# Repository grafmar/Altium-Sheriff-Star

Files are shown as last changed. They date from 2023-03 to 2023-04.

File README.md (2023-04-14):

# Altium-Sheriff-Star
PCB with Sherif-Star shape and 6 animated LEDs on it. It has the Altium Logo on the front and the Text "SHERIFF".
I also designed a holder to display the sheriff star on your desk.

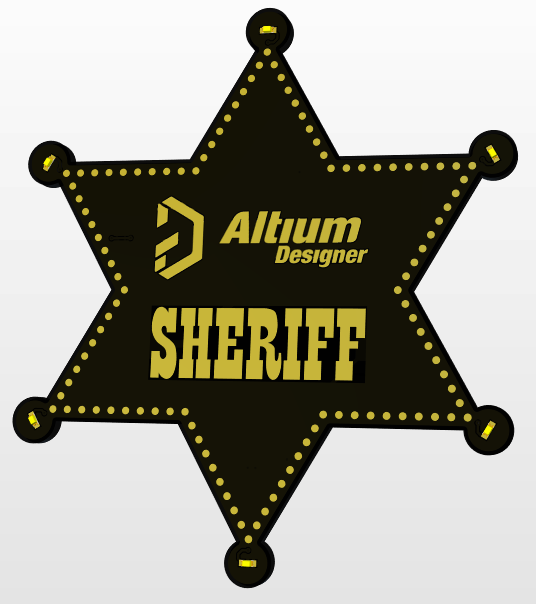
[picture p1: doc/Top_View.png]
PCB Top View
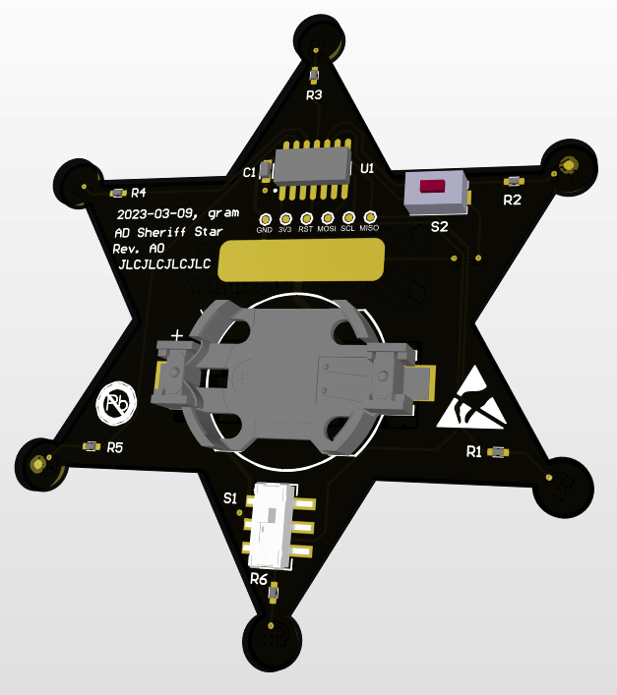
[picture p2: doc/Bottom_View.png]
PCB Bottom View
Animated GIF  

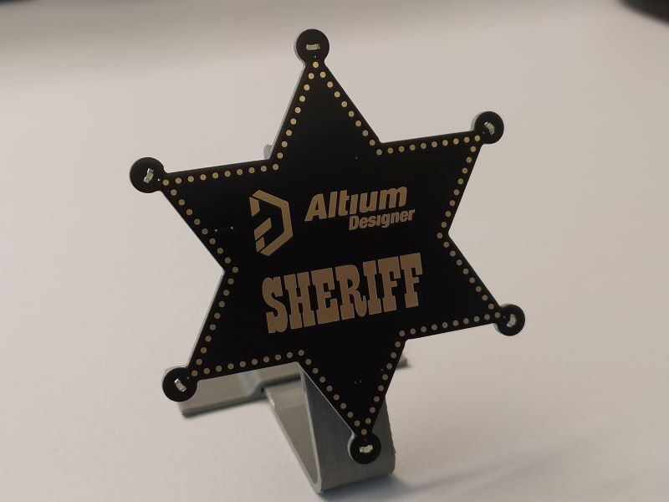
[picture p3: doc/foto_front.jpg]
Foto Front
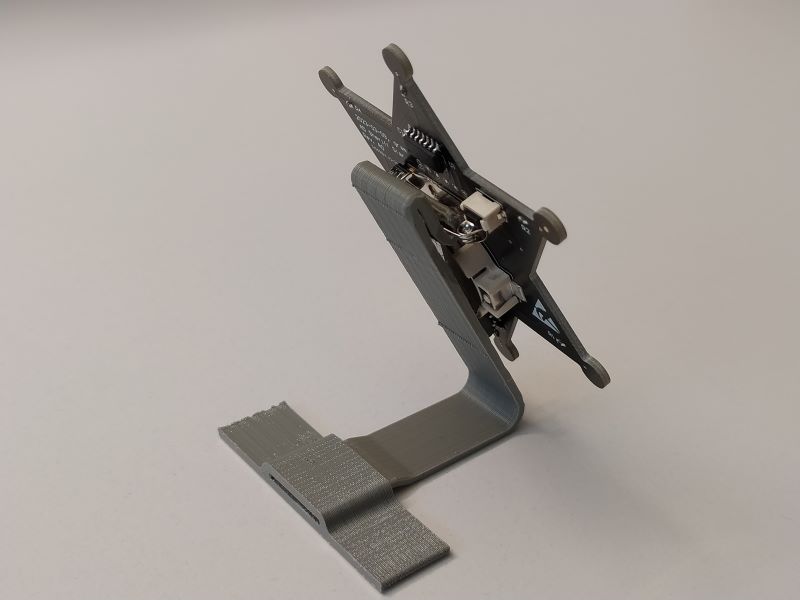
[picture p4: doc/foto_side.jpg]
Foto Side
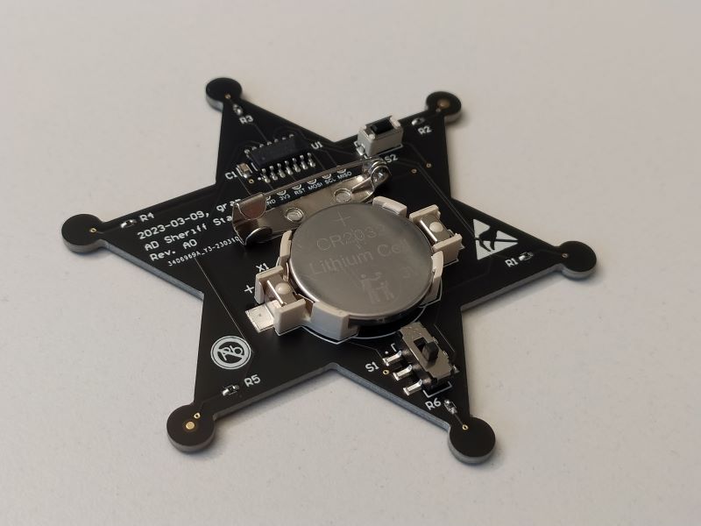
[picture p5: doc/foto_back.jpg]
Foto Back
  

## SW-Requirements
* [Arduino IDE](https://www.arduino.cc/en/main/software) (V 2.0.4)
* Board support "ATtiny/ATmega Standalone" (V 0.1.0)

## Hardware
The hardware consists of:
* [PCB Altium Sheriff Star](https://github.com/grafmar/Altium-Sheriff-Star/tree/main/pcb):
  * 6x Yellow LED 0603
  * 6x 100&Omega; 0402
  * 1x ATTINY84A-SSU
  * 1x CR2032 holder with CR2032 battery (Renata, SMTU2032-LF)
  * 1x slide switch (C&K, JS202011SCQN)
  * 1x tactile switch (Alps, SKQMASE010)
  * 1x 100nF 060
  * 1x 25mm [Safety Pins Brooch](https://www.aliexpress.com/item/4000026759489.html)

Schematics:

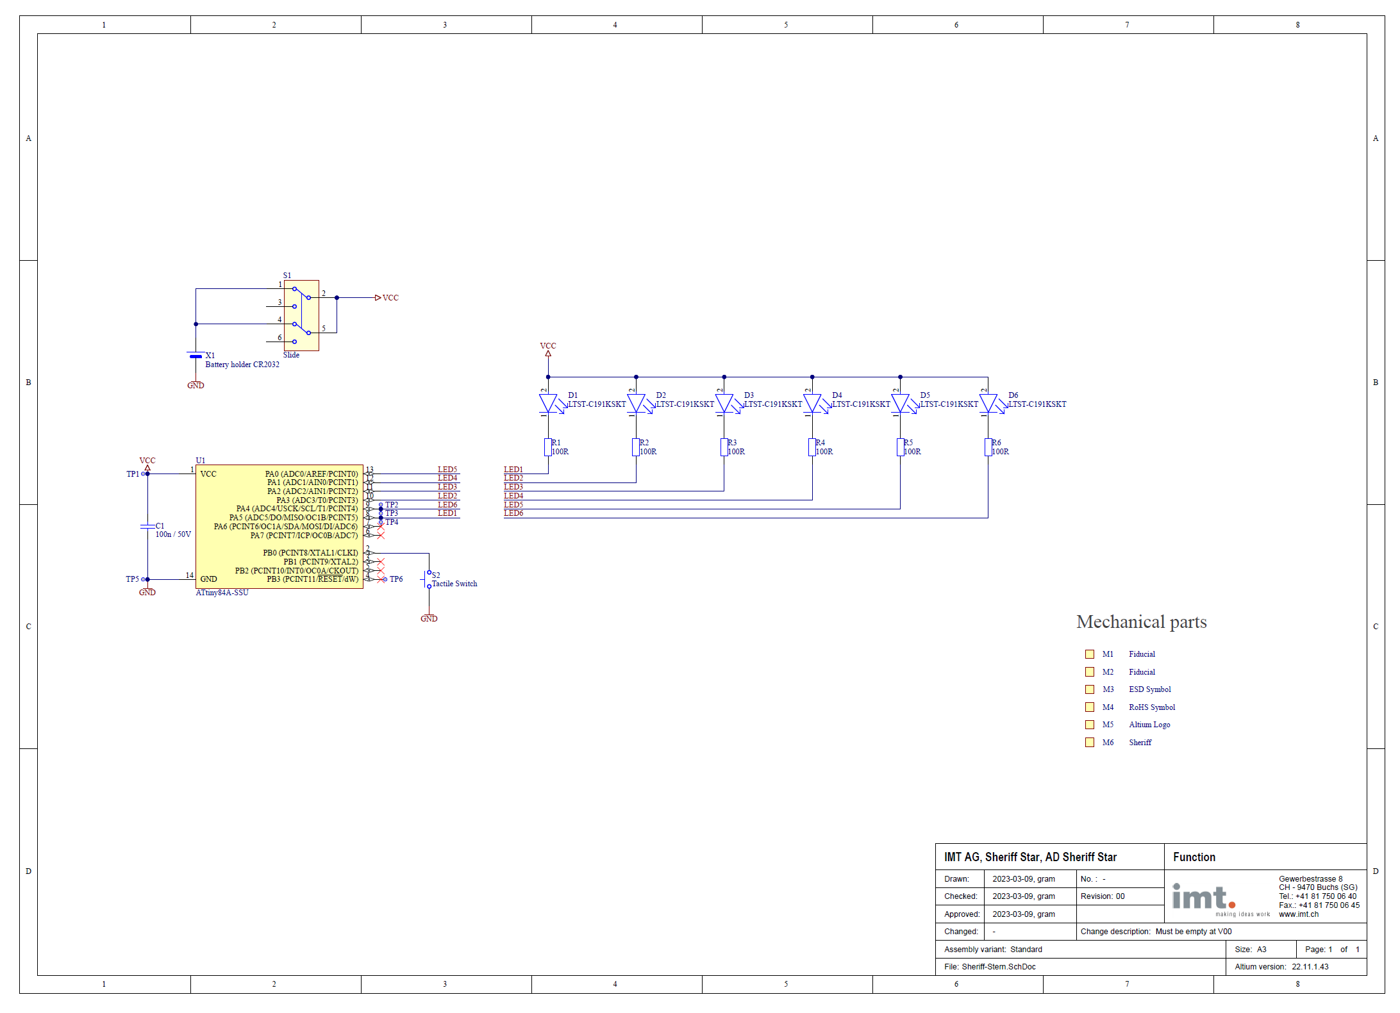
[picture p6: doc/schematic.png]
Schematics
[](pcb/30%20Production%20data/Rev00,%20A0/Schematic%20AD%20Sheriff%20Star%20Sheriff%20Star%20Rev00.PDF)

## Holder
The holder is designed in [FreeCAD](https://www.freecad.org/) and printed on a 3D printer. It has a small groove on the top to put the needle in. Like this it stands stable on the office table.

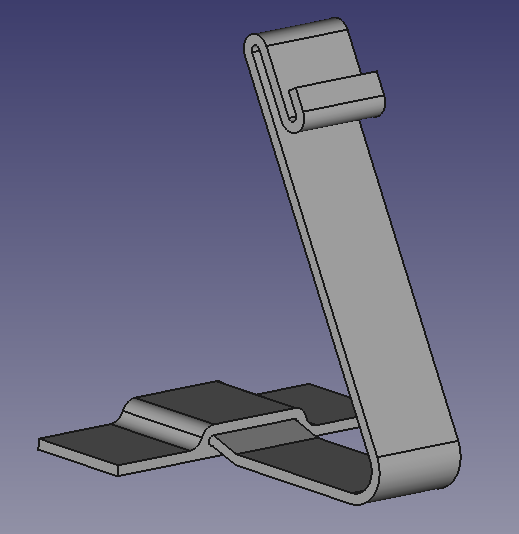
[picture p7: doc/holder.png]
Holder
 

## Author
[Marco Graf](https://github.com/grafmar)

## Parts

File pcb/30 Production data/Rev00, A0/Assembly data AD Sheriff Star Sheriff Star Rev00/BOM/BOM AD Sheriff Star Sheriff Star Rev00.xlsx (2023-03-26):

CUSTOMER, PROJECT |  |  | <Parameter VarCustomer not found> | <Parameter VarProjectName not found> | NUMBER | DESCRIPTION |  | REVISION
IMT AG, Sheriff Star |  |  |  |  | - | AD Sheriff Star |  | 00
CREATED |  |  |  |  | ASSEMBLY VARIANT
2023-03-09, gram |  |  |  |  | Standard
CHECKED
2023-03-09, gram
APPROVED
2023-03-09, gram
CHANGED |  |  |  |  | CHANGE DESCRIPTION
- |  |  |  |  | -
Fitted | Quantity | Designator | IMT Part Number | Customer Part Number | Description | Manufacturer | Manufacturer Part Number
Fitted | 1 | C1 | 11011700 |  | Cap 100n 50V 10% X7R 0603 | Kemet | C0603C104K5RAC
Fitted | 1 | D1 | CMP-22017-000025-1 |  | LED YELLOW CLEAR SMD | Vishay Lite-On | LTST-C191KSKT
Fitted | 1 | D2 | CMP-22017-000025-1 |  | LED YELLOW CLEAR SMD | Vishay Lite-On | LTST-C191KSKT
Fitted | 1 | D3 | CMP-22017-000025-1 |  | LED YELLOW CLEAR SMD | Vishay Lite-On | LTST-C191KSKT
Fitted | 1 | D4 | CMP-22017-000025-1 |  | LED YELLOW CLEAR SMD | Vishay Lite-On | LTST-C191KSKT
Fitted | 1 | D5 | CMP-22017-000025-1 |  | LED YELLOW CLEAR SMD | Vishay Lite-On | LTST-C191KSKT
Fitted | 1 | D6 | CMP-22017-000025-1 |  | LED YELLOW CLEAR SMD | Vishay Lite-On | LTST-C191KSKT
Fitted | 1 | R1 | 11001400 |  | Res 100R 1% 63mW 100ppm 50V 0402 | Vishay | CRCW0402100RFK
Fitted | 1 | R2 | 11001400 |  | Res 100R 1% 63mW 100ppm 50V 0402 | Vishay | CRCW0402100RFK
Fitted | 1 | R3 | 11001400 |  | Res 100R 1% 63mW 100ppm 50V 0402 | Vishay | CRCW0402100RFK
Fitted | 1 | R4 | 11001400 |  | Res 100R 1% 63mW 100ppm 50V 0402 | Vishay | CRCW0402100RFK
Fitted | 1 | R5 | 11001400 |  | Res 100R 1% 63mW 100ppm 50V 0402 | Vishay | CRCW0402100RFK
Fitted | 1 | R6 | 11001400 |  | Res 100R 1% 63mW 100ppm 50V 0402 | Vishay | CRCW0402100RFK
Fitted | 1 | S1 | 11152900 |  | Switch SMT slide DPDT C&K JS202011SCQN 300mA 6V | C&K | JS202011SCQN
Fitted | 1 | S2 | 11070700 |  | Switch SMT Tactile 1xSPST-NO ALPS SKQMASE010 50mA/12VDC | Alps | SKQMASE010
Fitted | 1 | U1 | CMP-0093-00274-1 |  | 8-bit AVR Microcontroller, 20MHz, 1.8-5.5V, 8KB Flash, 512 Bytes EEPROM, 512 Bytes SRAM, 14-pin SOIC, Industrial Grade (-40°C to 85°C), Pb-Free | Microchip | ATTINY84A-SSU
Fitted | 1 | X1 | 11130300 |  | Con SMT Renata SMTU Battery holder CR2032 | Renata | SMTU2032-LF

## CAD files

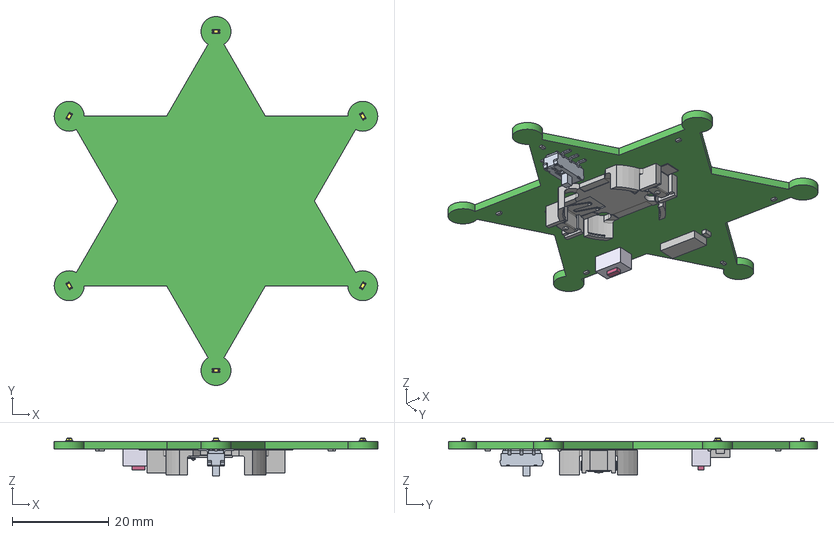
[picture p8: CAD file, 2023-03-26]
pcb/30 Production data/Rev00, A0/STEP AD Sheriff Star Sheriff Star Rev00, A0.step
66.8 x 76.2 x 7.75 mm
Lite-On Logo Adjustable x 6
Extruded x 10
SW3DPS-BATT HOLDER (SMTU2032-LF)-DEFAULT_RGB8421504
JS202011SCQN

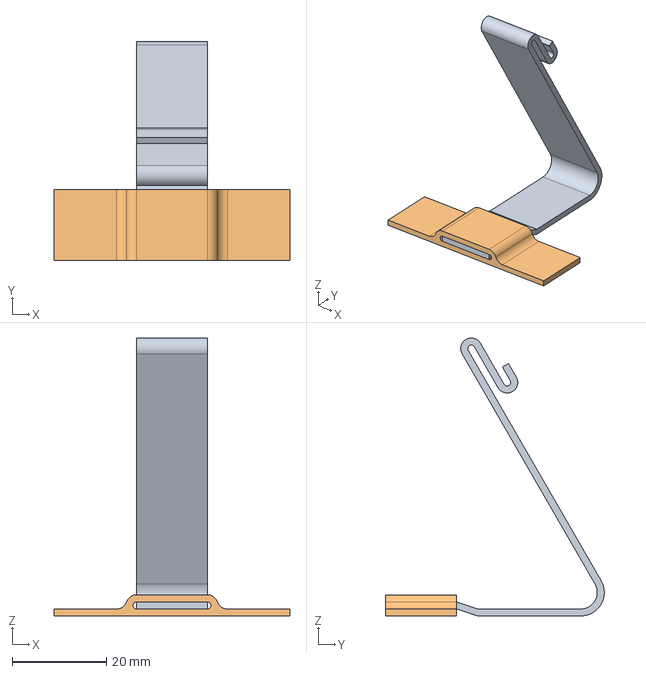
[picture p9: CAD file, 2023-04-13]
holder/Sheriff-Star-Holder.FCStd
50.0 x 46.3 x 58.9 mm
BodyCross

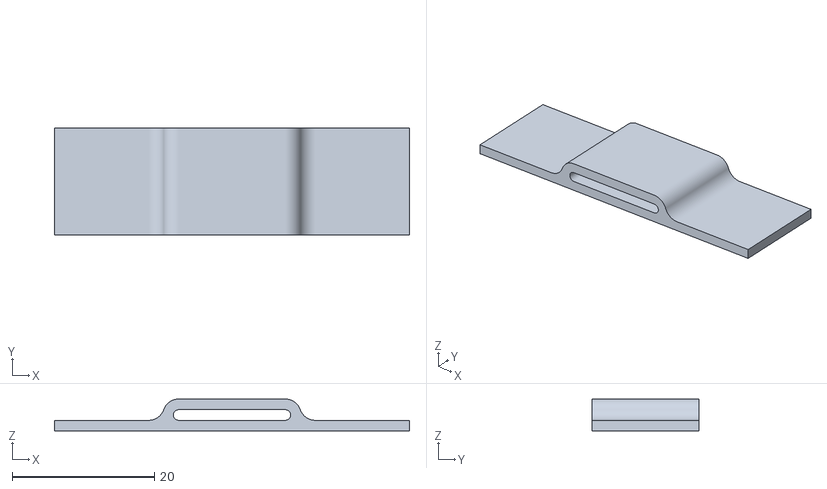
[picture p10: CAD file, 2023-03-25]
holder/Sheriff-Star-Holder-BodyCross.stl
50.0 x 15.0 x 4.50

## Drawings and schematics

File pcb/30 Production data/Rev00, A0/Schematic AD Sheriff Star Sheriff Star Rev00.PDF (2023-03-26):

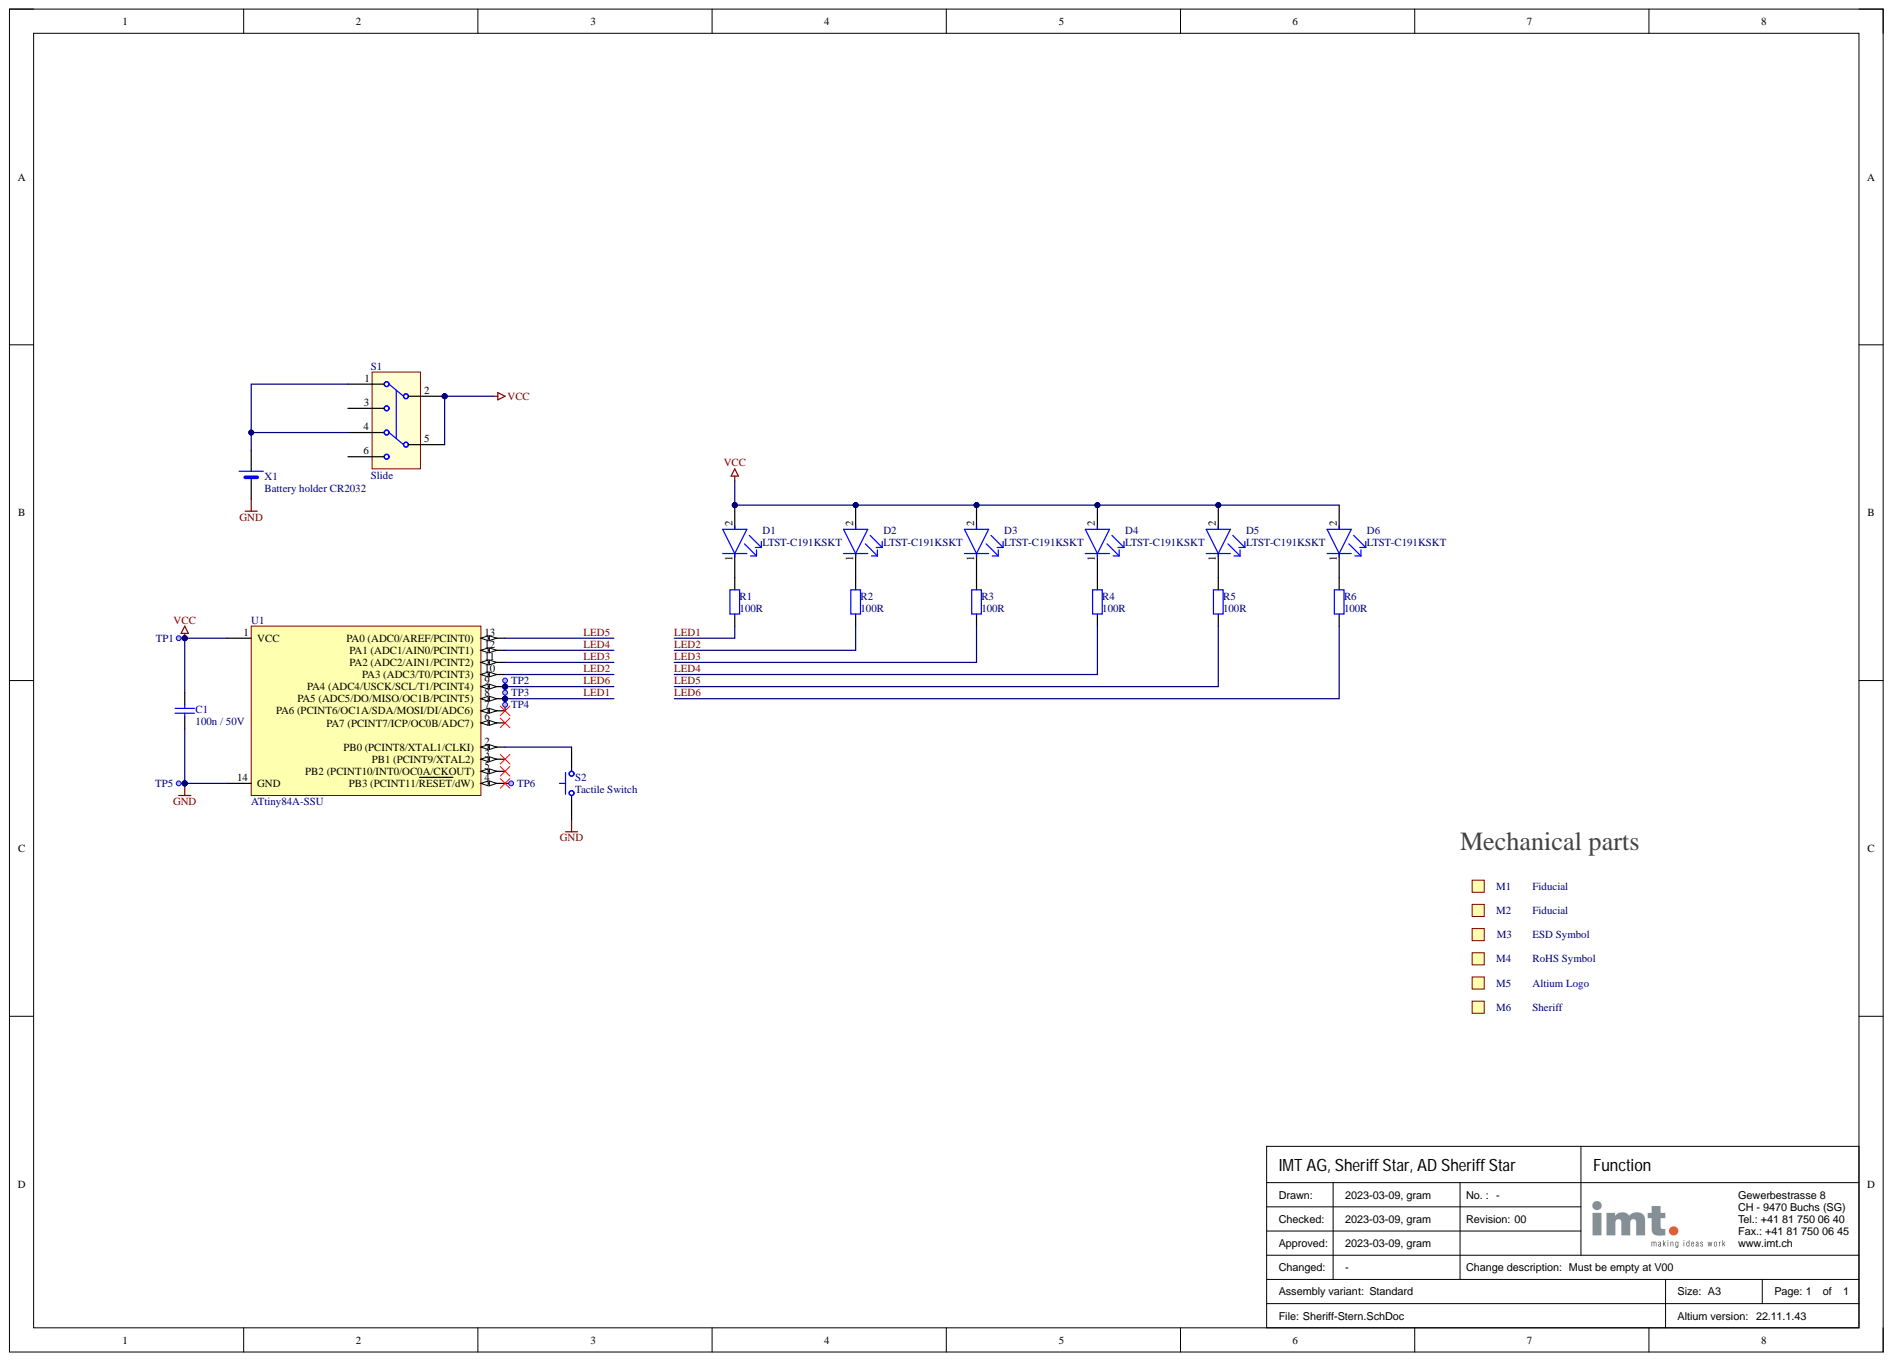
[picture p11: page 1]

IMT AG, Sheriff Star, AD Sheriff Star | Function

Drawn : | 2023-03-09, gram | No. : - | Gewerbestrasse 8 CH - 9470 Buchs (SG) Tel.: +41 81 750 06 40 Fax.: +41 81 750 06 45 www.imt.c h

Checked : | 2023-03-09, gram | Revision : 00

Approved : | 2023-03-09, gram

Changed : | - Change description: Must be empty at V00

Assembly variant: Standar d | Size : A3 | Page : 1 of 1

File : Sheriff-Stern.Sch D o c | Altium version: 22.11.1.4 3

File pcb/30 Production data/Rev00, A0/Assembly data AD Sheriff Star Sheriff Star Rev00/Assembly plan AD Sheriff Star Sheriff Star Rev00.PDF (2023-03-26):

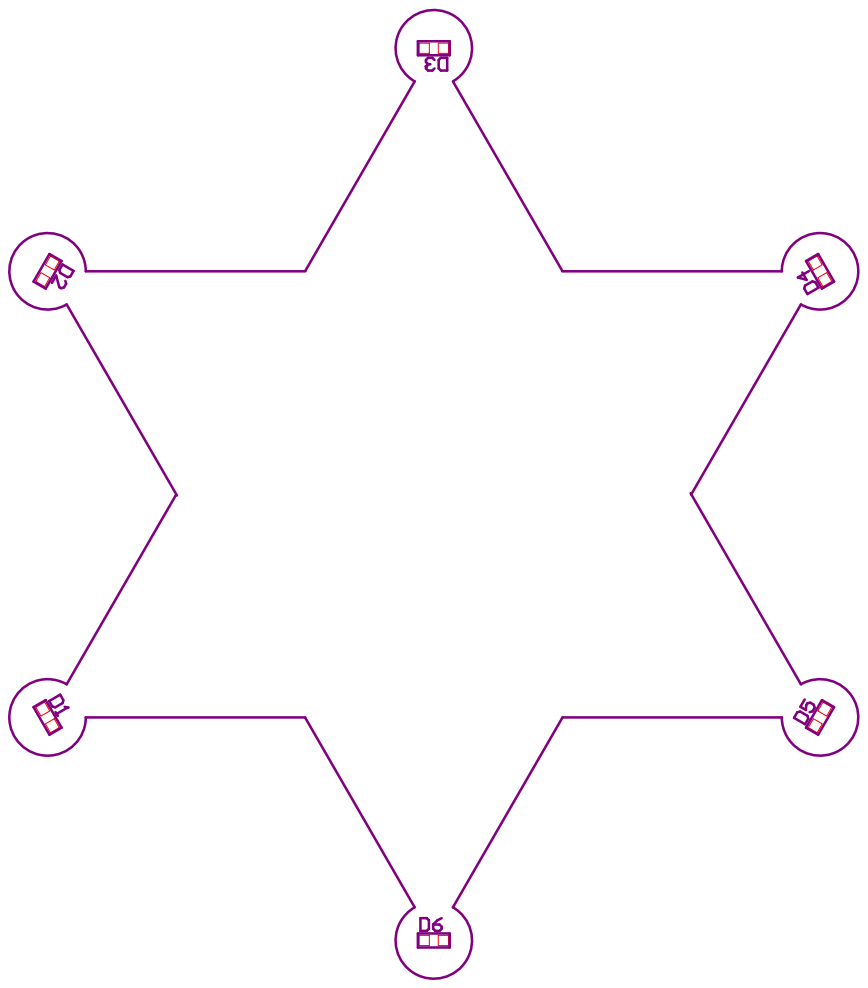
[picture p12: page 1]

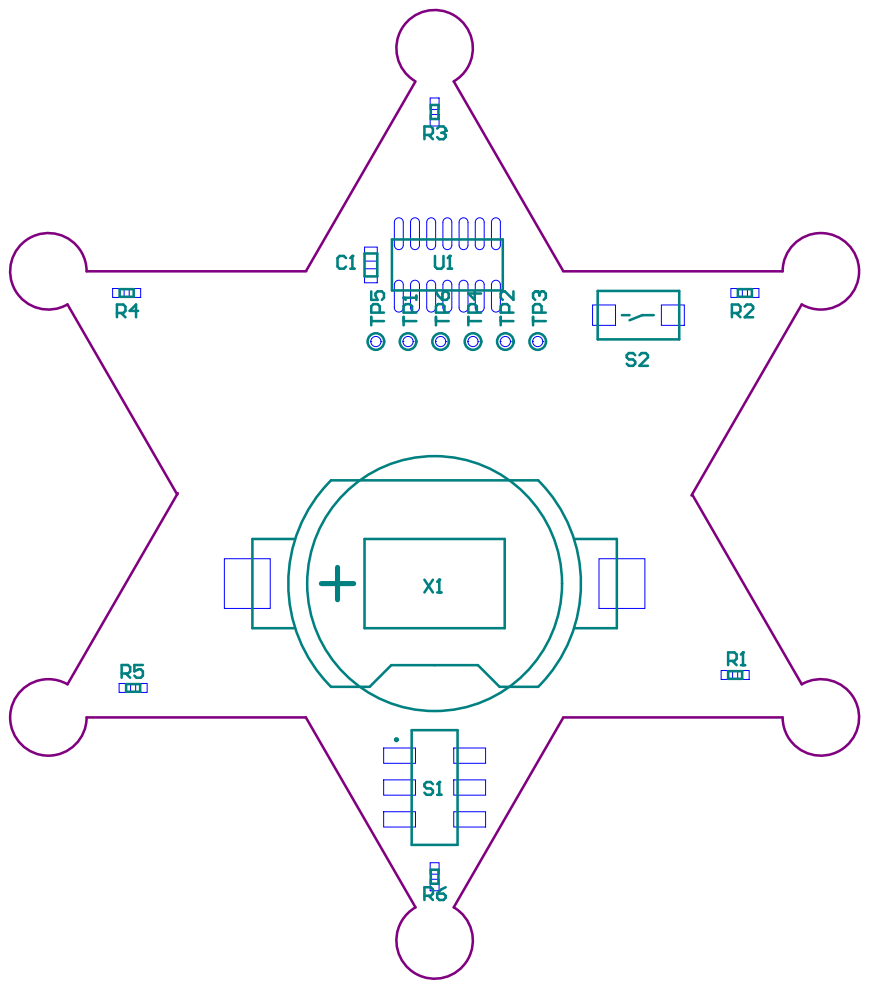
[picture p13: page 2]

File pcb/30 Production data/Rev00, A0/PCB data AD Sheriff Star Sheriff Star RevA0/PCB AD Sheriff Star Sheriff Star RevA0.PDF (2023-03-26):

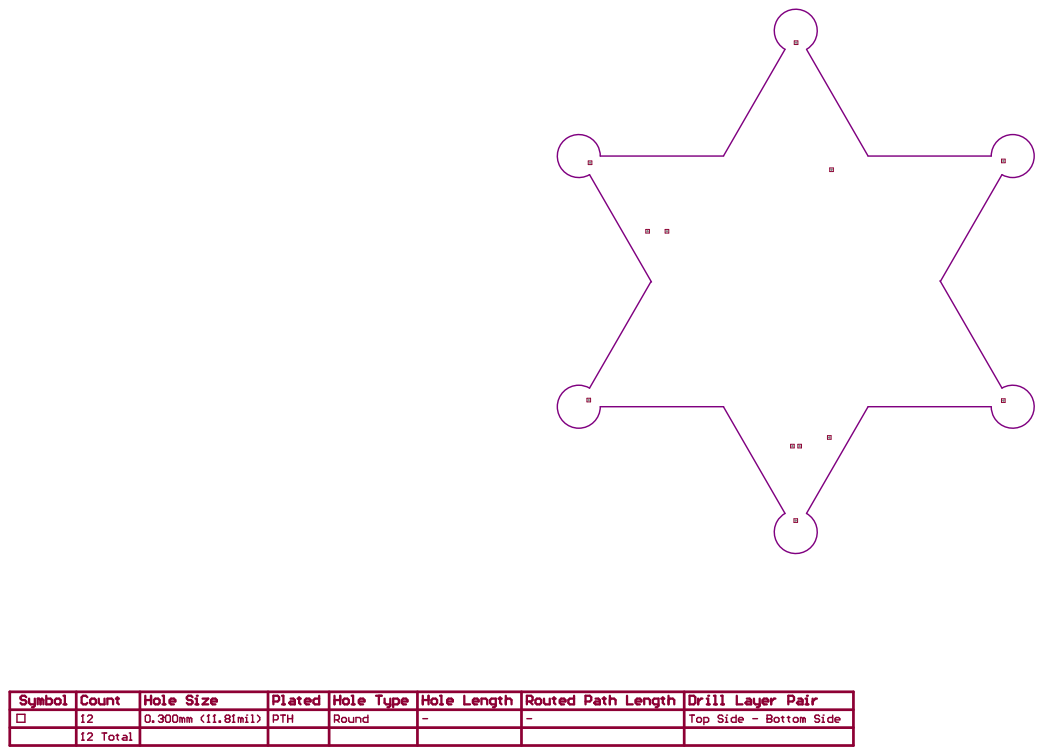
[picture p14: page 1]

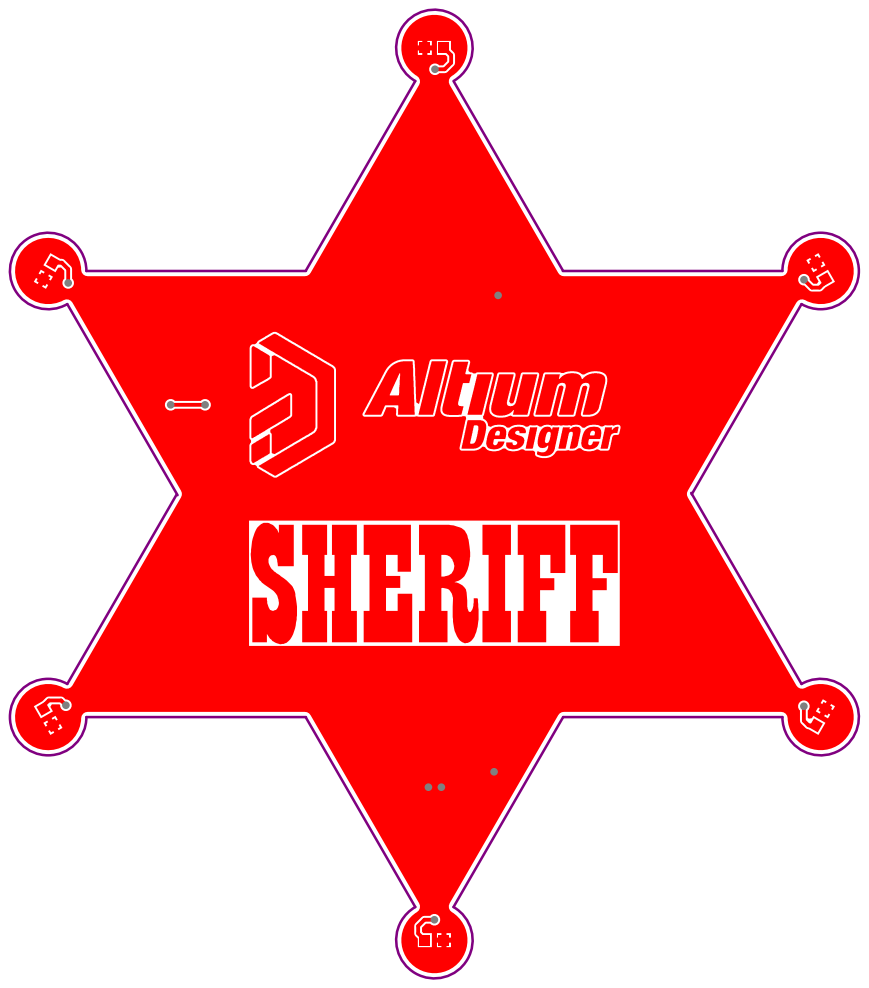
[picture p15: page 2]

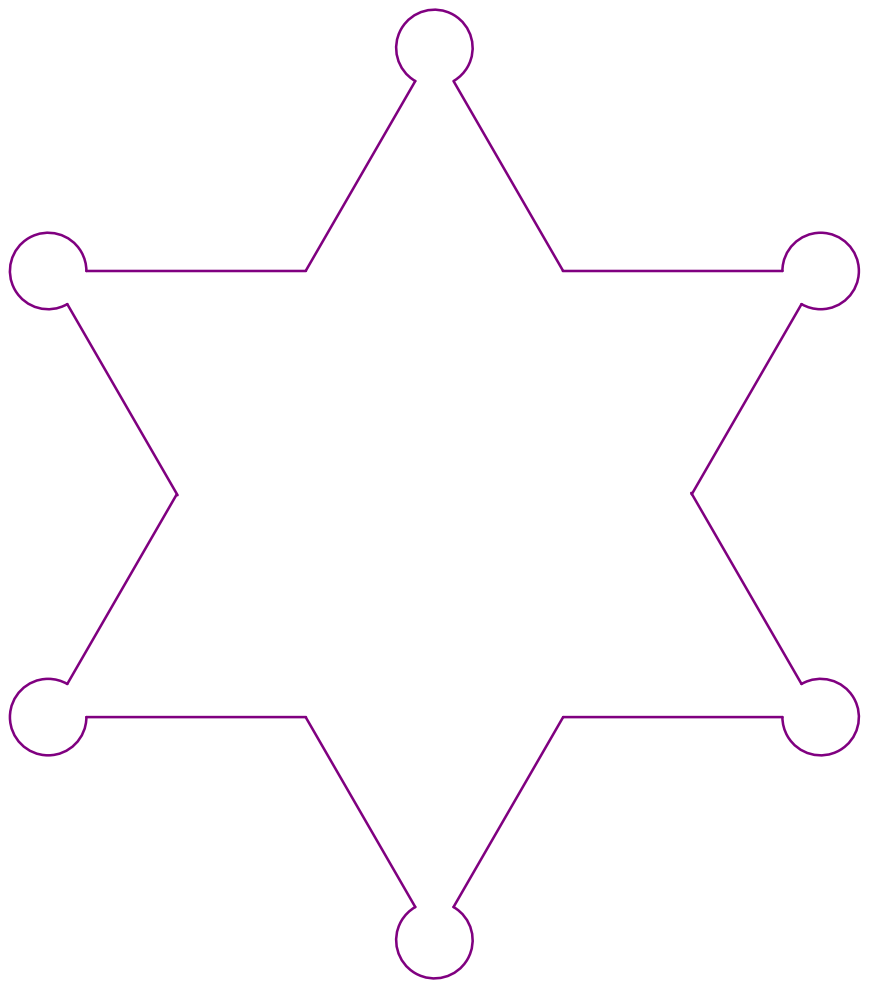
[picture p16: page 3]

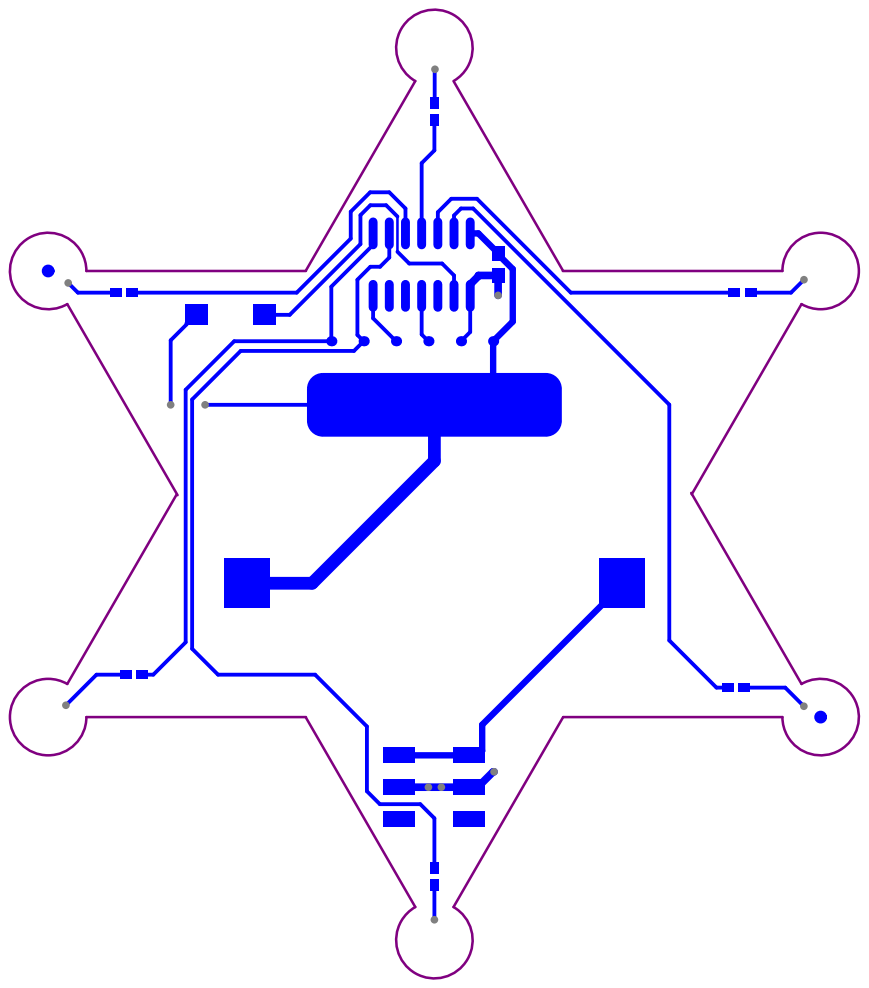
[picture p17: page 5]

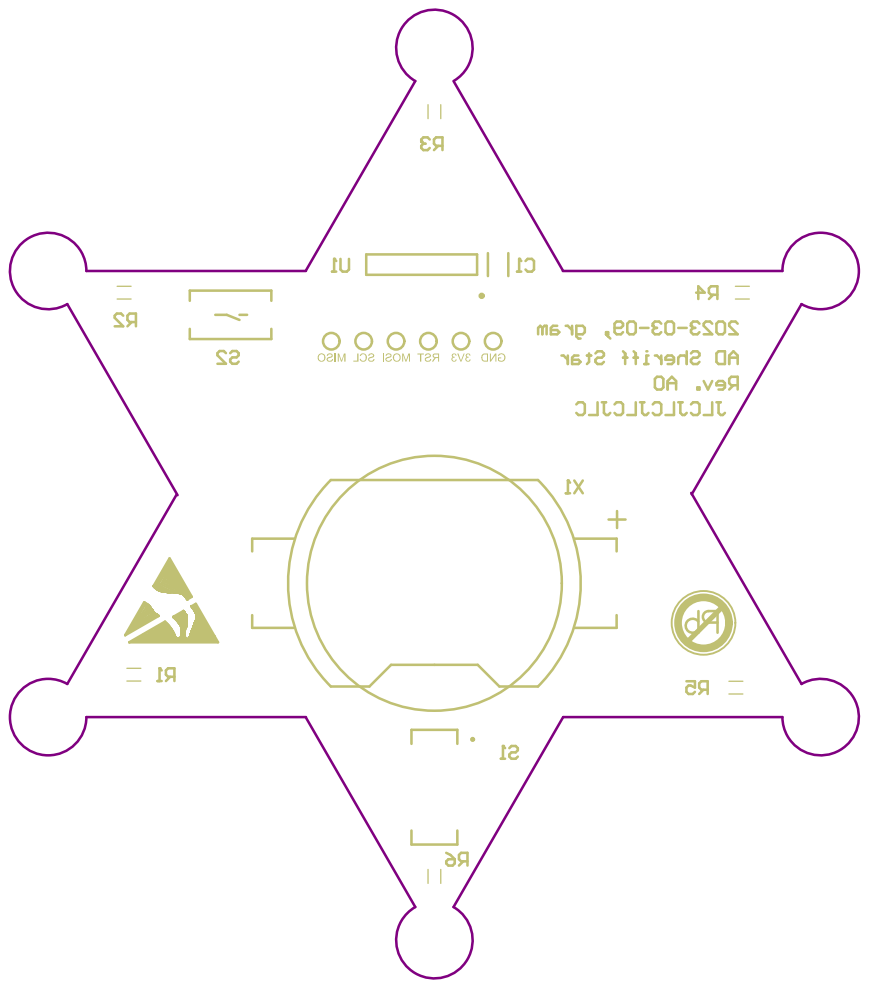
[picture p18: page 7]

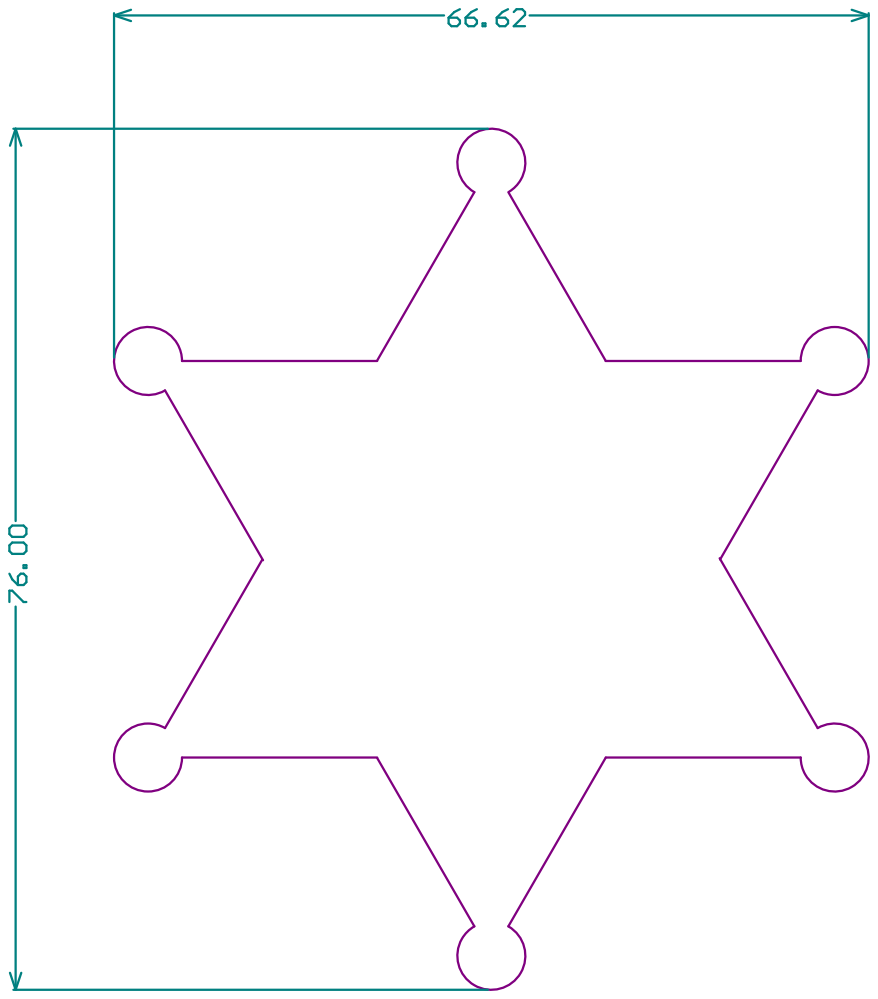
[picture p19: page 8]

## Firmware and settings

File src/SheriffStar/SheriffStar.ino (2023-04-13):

/*
  ATTINY LED control to show different patterns and programs on 6 LEDs
  One button is read in to select the program
*/

const int buttonPin = 10;

uint32_t buttonTime = 0U;
bool buttonStateLast = false;
bool buttonStateDebounced = false;
bool buttonEvent = false;

void debounceButton();


void setup() {
  // initialize input and output pins
  pinMode(buttonPin, INPUT_PULLUP);
  pinMode(5, OUTPUT);
  pinMode(3, OUTPUT);
  pinMode(2, OUTPUT);
  pinMode(1, OUTPUT);
  pinMode(0, OUTPUT);
  pinMode(4, OUTPUT);
}


void loop() {
  // debounce the button which sets the buttonEvent for one cycle if a button is pressed
  debounceButton();
  
  // if the button is pressed, change to the next program
  if (buttonEvent) {
    setNextProgram();
  }

  // evaluate the program, which also sets the LEDs
  evalProgram();
}


void debounceButton() {
  bool buttonState = (digitalRead(buttonPin) == LOW);   // read the state of the button
  uint32_t now = millis();                              // get milliseconds from start as time reference
  buttonEvent = false;                                  // reset the buttonEvent

  if (buttonState != buttonStateDebounced) {            // only check if the button state is different than the debounced state
    if (buttonState != buttonStateLast) {               // if the button state changed since last time reset the timer
      buttonTime = now;
    }

    if ((now-buttonTime)> 30U) {                        // if state is stable for 30ms:
      buttonStateDebounced = buttonState;               //   set debounced state
      if (buttonState) {                                
        buttonEvent = true;                             //   set the buttonEvent (only if the button is pressed)
      }
    }
  }
  buttonStateLast = buttonState;                        // store the buttonState for the next check
}

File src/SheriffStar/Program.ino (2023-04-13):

uint8_t leds;
uint32_t lastProgStep = 0U;
uint8_t program_set = 0U;
bool showProgramNumber = false;

uint32_t progSetTime = 0U;

static const uint8_t NUM_OF_PROGRAMS = 7U;
static const uint32_t SHOW_PROGRAM_NUMBER_TIME = 1000U;


void setNextProgram() {
  progSetTime = millis();
  lastProgStep = progSetTime;
  showProgramNumber = true;
  program_set = (program_set + 1)% NUM_OF_PROGRAMS;
}

void evalProgram() {
  if (showProgramNumber) {
    if ((millis() - progSetTime) > SHOW_PROGRAM_NUMBER_TIME) {
      showProgramNumber = false;
    }
    if (program_set >= NUM_OF_LEDS) {
      setLED(0x20 | (0x01U<<(program_set-NUM_OF_LEDS)));
    } else {
      setLED(0x01U<<program_set);
    }
  }
  else {
    if (program_set == 0U) {
      // automatic change every 5s
      applyProgram(1U + (millis()/5000)%(NUM_OF_PROGRAMS-1));
    } else {
      applyProgram(program_set);
    }
  }
}

void applyProgram(uint8_t prog) {
  // evaluate program
  uint32_t now = millis();
  uint32_t nowUs = micros();
  static const uint32_t pwmFactor = 20000; // with micros this are 50Hz
  static const uint32_t pwmMinValue = 2000; // Low PWM values are difficult. Therefore set values below pwmMinValue to zero

    switch(prog) {
    case 0U: // automatic change - no program
      break;

    case 1U:
      // one on after the other all 100ms (all others off)
      leds = 0x01<<((now/100UL) % NUM_OF_LEDS);
      break;

    case 2U:
      // one off after the other all 100ms (all others on)
      leds = ~(0x01<<((now/100UL) % NUM_OF_LEDS));
      break;

    case 3U:
      // all 100ms randomly only one LED on
      if ((now - lastProgStep) > 100U) {
        lastProgStep = now;
        leds = 0x01<<random(5);
      }
      break;

    case 4U:
      // all 100ms randomly which are on or off (random patterns every 100ms)
      if ((now - lastProgStep) > 100U) {
        lastProgStep = now;
        leds = random(0xFF);
      }
      break;

    case 5U:
      // dimming up and down all LEDs together every 2s
      {
        float value = (1+sin(now/318.0))/2 * pwmFactor; // 2000/(2pi) = 318
        if (value < pwmMinValue) value = 0U; // Set values below pwmMinValue to zero
        if (value > (nowUs % pwmFactor)) {
          leds = 0xFF;
        } else {
          leds = 0x00;
        }
      }
      break;

    case 6U:
      // dimming up and down all LEDs in a circle every 2s (go around in a circly dimming up and down)
      {
        const float two_pi_6th = 2.0 * 3.1415926535897932384626433 / 6.0;
        leds = 0x00;
        for (uint8_t i=0; i<6U; i++) {
          leds = leds<<1;
          // float value = (1 + sin(now/318.0 + two_pi_6th*i))/2*25; // 2000/(2pi) = 318
          float value = ((1 + sin(now/318.0 + two_pi_6th*i))/2); // 2000/(2pi) = 318
          value = value * value; // square for more low level
          value = value * pwmFactor; // scale with PWM-value (60)
          if (value < pwmMinValue) value = 0U; // Set values below pwmMinValue to zero
          if (value > (nowUs % pwmFactor)) {
            leds |= 0x01;
          }
        }

        // this isn't faster
        // static const uint8_t lookup[20] = {15,26,38,49,57,60,57,49,38,26,15,7,3,1,0,0,0,1,3,7}; // offset sinus squared scaled by 60
        // leds = 0x00;
        // for (uint8_t i=0; i<6U; i++) {
        //   leds = leds<<1;
        //   if (lookup[(now/100)%20] > (now%60)) {
        //     leds |= 0x01;
        //   }
        // }
      }
      break;

    default:
    break;      
  }
  setLED(leds);
}

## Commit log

2023-03-25 Added Sheriff Star Holder files
    [Sheriff-Star-Holder-Body.stl, Sheriff-Star-Holder-BodyCross.stl, Sheriff-Star-Holder.FCStd]
2023-03-25 some additional test trying to getting it a smoother PWM
2023-03-26 Using microseconds instead of milliseconds for PWM generation. Set PWM frequency to 50Hz and set PWM values below certain level to zero to avoid flashing LEDs at low PWM levels
    [Program.ino]
2023-03-26 added PCB data
    [BOM AD Sheriff Star Sheriff Star Rev00.xlsx, BOQ AD Sheriff Star Sheriff Star Rev00.xlsx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]
2023-03-27 Add image of schematic to readme documentation
2023-03-29 adapted showing Program on LEDs for 6 LEDs added HEX binary
2023-03-29 Modification on the hanger to make it more stable: longer upper part smaller diameter on the bottom front
    [Sheriff-Star-Holder-Body.stl, Sheriff-Star-Holder.FCStd]
2023-04-13 Added safety pin to HW material in README.md
